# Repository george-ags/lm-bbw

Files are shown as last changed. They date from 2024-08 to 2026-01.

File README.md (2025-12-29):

# LM-BBW (brew-by-weight) for La Marzocco Linea Micra machine & Acaia Lunar scale

This given work is forked and based on Marcus Sorensen's "apollo" project 
(https://github.com/mlsorensen/apollo) - with big thanks and high appreciation !

LM-BBW helps land espresso on your Lunar scale. This project adds brew-by-weight and a small controller 
for La Marzocco Micra with Acaia Lunar. It may also work with other Acaia Bluetooth scales like Pyxis. 

I should fully rewrite some files (like control.py and pyacaia.py to port it to Debian 12/13+ with some improvements)

This project is more about scale integration than Micra integration. It cannot do flow profiling or other advanced 
control over the Micra, it is simply collecting data from the scale and acting as a proxy for the paddle switch.

**This is a hobby project, as such there is no support.** It is sort of a hack/proof of concept being beaten into shape.
Contributions are welcome, though this is very much designed to work according to my needs, for customization I'd 
suggest forking and making it your own.

# UPDATES

## Umbra support
I've added support for the Acaia Umbra scale, which is very similar to the Lunar scale, but it lacks a display and onboard
controls. This is ideal for integrations. Aside from being much less expensive. it is a bonus not to have to deal with 
accidentally touching controls. The full blank slab is also nice aesthetically.  Additionally, it has a "sleep" mode. This 
enables LM-BBW to just connect to the scale when needed, and the scale will go to sleep when disconnected - you don't need 
to touch the scale at all except occasionally to charge or clean it!

To accomodate this I've made one fundamental adjustment. I've comandeered the "target lock" toggle switch to become a 
"connect" button. In over a year I never used this button anyway. When depressed, it will connect to the scale and turn 
on the screen. When disabled it will disconnect and the screen will turn off. For a regular Lunar scale, simply leave the 
toggle depressed and you can continue to manage the system by turning on/off the Lunar as before.

## Horizontal display
This is a part of an effort to build a nicer enclosure, building the device into the top panel of the Micra. All of the
wiring and setup below still applies, with the exception of printing a new top panel and using 8mm push switches in place
of the toggle switch to select target weight.

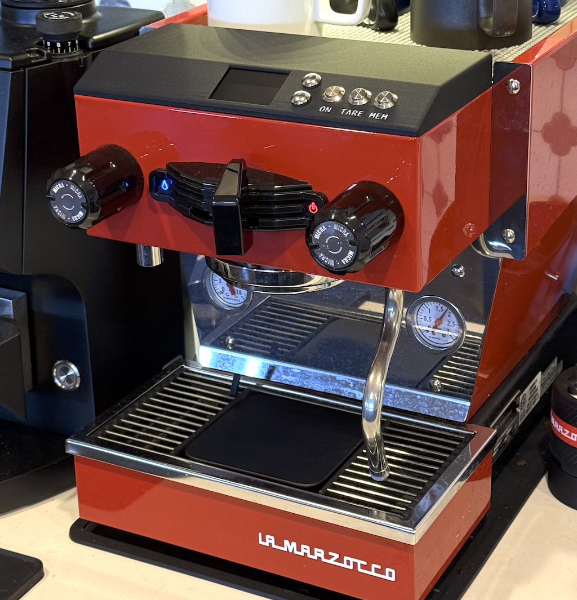
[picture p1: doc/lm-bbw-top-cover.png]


The "LM-bbw top cover" 3d printing models are in the doc folder.

In my setup I migrated from the Pi Zero 2W to the Raspberry Pi 5, which is overkill CPU-wise and I actually underclock to
1600MHz, but it gives smoother frame rates. I'm sure a Pi 4 or 3 would work too. I use the lite Raspbian image since we 
don't need a full GUI. I insulate the back of the device with tape and tuck it in the open space on the right near the 
steam wand.

I have monitored temperatures closely and not experienced a high enough temperature to throttle the Pi while installed. 
Consider printing the top cover in something more heat resistant like ABS or ASA. I printed in PLA Carbon Fiber for a 
nice texture, rated to withstand 55C, and I've coated the bottom inside shell with a thin layer of neoprene foam. So far 
I haven't seen the top exceed 42C.

I have replaced the top cover screws with M4-0.7 screws made of non-stainless and added 10mm magnets into the top
cover to hold it in place without visible fasteners.

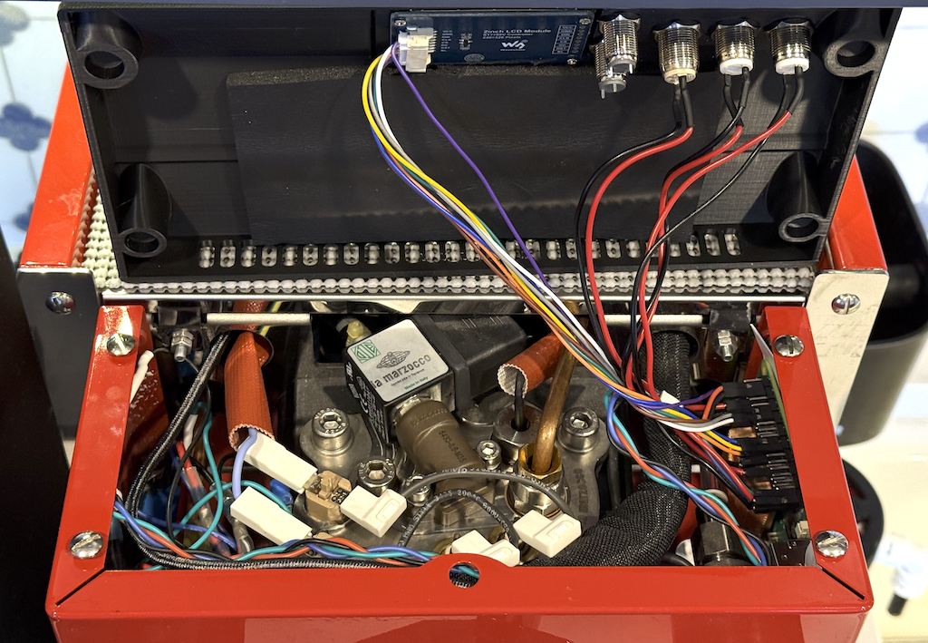
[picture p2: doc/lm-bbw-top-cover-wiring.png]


## Configuration variables
There are some new variables to control framerates and display orientation at `/etc/default/lm-bbw`, documented in the
comments of this file (aka `service/env` in this repo).

## Hardware

### Materials

Note that where external links are provided, they may not age well.

* A Raspberry Pi Zero 2W w/soldered header
* 5v relay w/3.3v compatible logic control
* 5v 2a power supply
* 2.1mm barrel jack connector/wiring harness
* pushbutton switch x 2
* toggle switch
* up/down rocker switch (or two pushbutton switches)
* 2" WaveShare 240x320 SPI display (or compatible)
* Screws - M2.0, M2.5 4mm length, or #3-24 in 1/4" length depending on your 3d printer tolerances
* Silicone 24AWG hook up wire
* Soldering tool and/or 2.54mm crimping set
* 3d printed enclosure, or self-provided alternative

### Controller

A Raspberry Pi was selected to accommodate easy adoption of existing Python libraries without having to
rework them to function on a microcontroller.  Ultimately this is more flexible in terms of expanding
functionality as well.

### Display

The software should support either the [WaveShare 2.0" display](https://www.waveshare.com/2inch-lcd-module.htm) 
or the [2.4" display](https://www.waveshare.com/2.4inch-lcd-module.htm). The 2.4" display seems to have worse
viewing angles and is less sharp, and display_size needs to be updated in `main()`. **For compatibility with the included enclosure, the 2" display should be used.**

### Relay

There isn't one specific relay to link to. Any 5v Arduino/Pi/ESP32 type relay should work. It will have 
common/NC/NO connections on the relay side and 5v/gnd/control pin on the controller side.

### Buttons

I use a momentary pushbutton switch for the tare and memory buttons, a toggle switch for the "scale connect" button,
and an up/down rocker switch for adjusting the target. The up/down rocker switch can be thought of as two momentary
switches with a common ground - you can use two separate buttons as well.

For compatibility with the included 3d printed enclosure, the buttons should be 12mm. The rocker switch should be
rectangular and support 19mm x 13mm opening. 

I found the quality of rocker switches a bit difficult, some had significant bounce leading to them being a bit tricky 
to use. I bought several kinds and used what worked best. The model I ended up using was `MXU1-2-123`.

### Wiring

I bought a crimping tool in order to finish off the connections with standard Dupont 2.54mm connectors for easy
wiring up to the Raspberry Pi header.



To simplify the wiring of power and controls between the Micra and the controller, I created a custom harness. This 
keeps the ground and power connections for the relay and switches in the Micra, with just 5v,ground and one wire
per IO going back to the controller (4 pins total).



The Micra paddle is accessible by removing the top four screws above the group head. Here, you would find a wiring
bundle containing black and white wires connecting to the paddle. These have bullet connectors which can be 
disconnected. You can insert the relay and Pi into this circuit to read the paddle state and control the Micra (or 
perhaps another device).

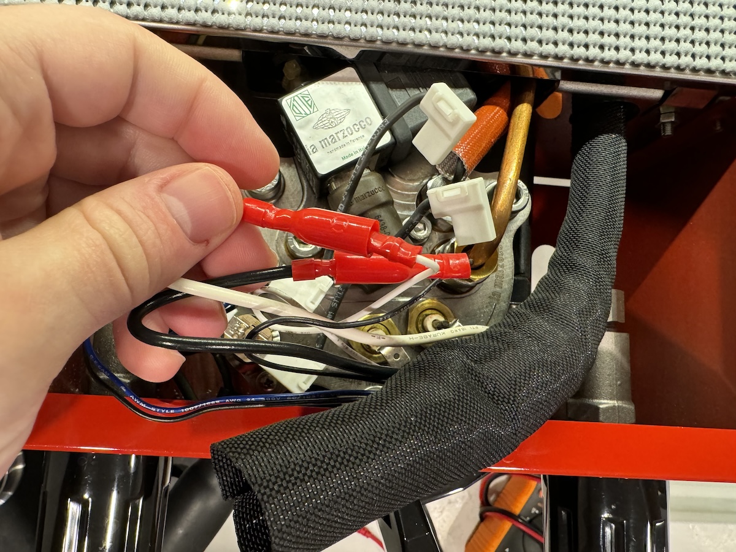
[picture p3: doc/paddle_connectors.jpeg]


### Enclosure

The enclosure STL file can be found [here](doc/LM-bbw_2inch_v2.stl). It may need fine tuning, depending on the accuracy
and tolerances of your printer.



Looking from the inside, the display mounts with four screws to the far side, along with the buttons.

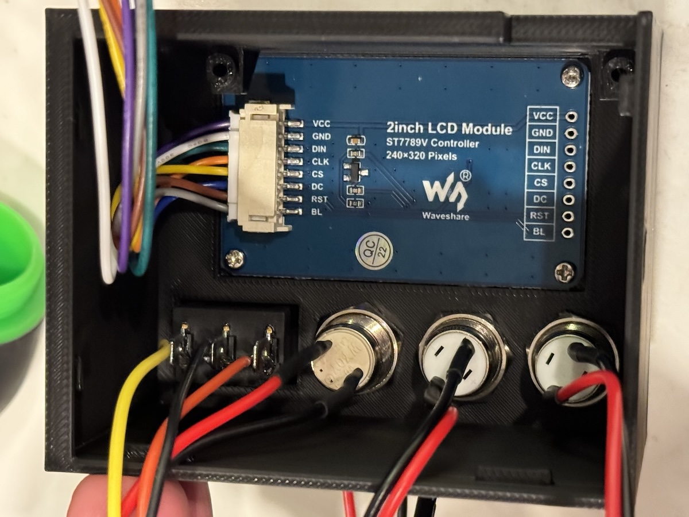
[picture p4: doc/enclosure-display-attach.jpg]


The Raspberry Pi mounts above the display, using the standoffs on the right. There are only two mounts for the Pi. 
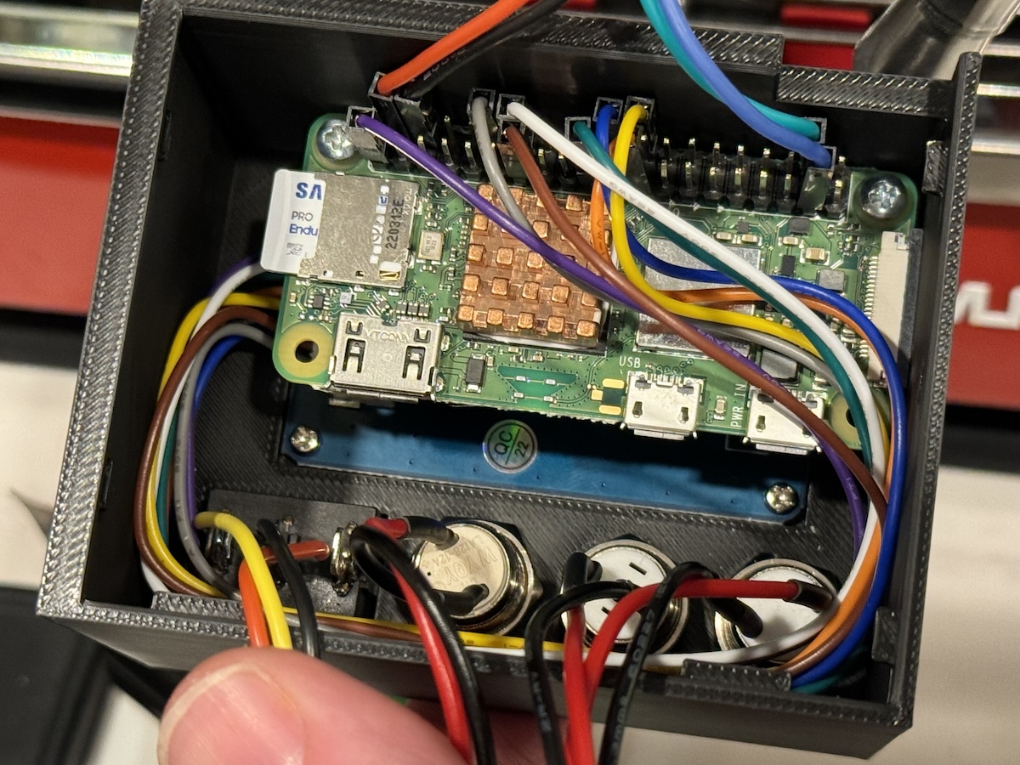
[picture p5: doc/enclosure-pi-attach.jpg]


In all cases be careful not to over-tighten. Ensure everything is connected properly. Route the wiring for the 
paddle/power through the cutout and then up into the group area through the open hole by the steam wand.

The backplate is designed to mount to the Micra on the right of the machine, using the large screw hole. Optional 8mm
magnets can be placed to aid installation and help secure the top of the plate.

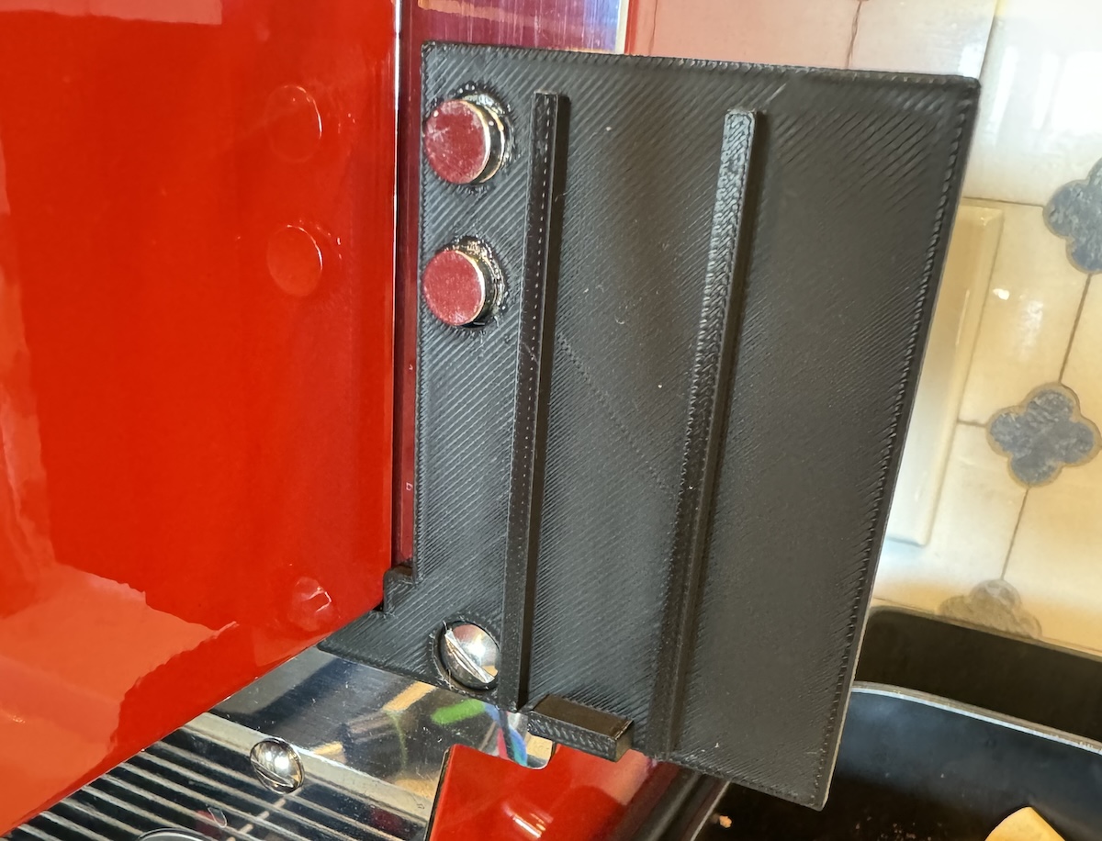
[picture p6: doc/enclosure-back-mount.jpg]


Then the enclosure hangs on the plate from the top clamshell-style. Once hung, a screw can be inserted to fasten the 
bottom of the enclosure to the plate.

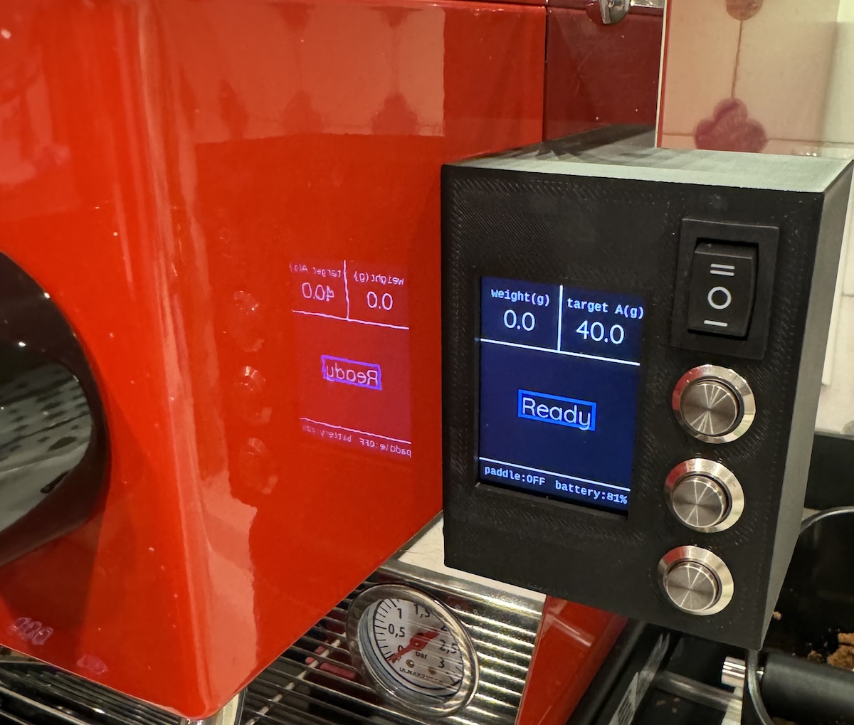
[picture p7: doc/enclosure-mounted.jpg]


## Software Installation

It is assumed you have a Raspberry Pi Debian distribution already installed. As of this writing,
Debian Bullseye is the recommended OS for the Pi Zero 2W. Other versions of Raspberry Pi may also
work.

### Display Driver

The SPI bus must be enabled to drive this display. Log into your Pi and run the following:

```commandline
sudo raspi-config
```

Choose Interfacing Options -> SPI -> Yes  to enable the SPI interface

Next, we want to release memory from the GPU for system use and thus change / set it to 16M.
(Note in Debian 11 it was in `raspi-config`, under Performance -> GPU Memory limit)
```commandline
sudo nano /boot/firmware/config.txt
```

Scroll to the bottom of the file and add, or modify, (best is under section [all]) the following line:
```commandline
gpu_mem=16
```

Finally, we want to disable the login UI. Under System Options -> Boot / Auto Login choose "Console" 

```commandline
sudo reboot
```

### Software dependencies

```commandline
sudo apt install python3-pandas python3-pip libglib2.0-dev git
sudo pip3 install bleak --break-system-packages
```

#### LM-BBW Software Installation and Activation

```
git clone https://github.com/george-ags/lm-bbw.git
cd lm-bbw
sudo mkdir -p /opt/lm-bbw/web
sudo cp -r lm-bbw.py lib /opt/lm-bbw
sudo chmod +x /opt/lm-bbw/lm-bbw.py
sudo cp service/lm-bbw.service /etc/systemd/system
sudo cp service/env /etc/default/lm-bbw
sudo systemctl daemon-reload
sudo systemctl enable --now lm-bbw
```

By default, the software scans for any Lunar device in the vicinity and connects to it. There is no simple
way to set a specific scale MAC address yet.

#### If it FAILS to start
 - check in Journalctl if Bluetooth adapter is found and it's powered On:
```commandline
bluetoothctl show
```
You should see Powered: yes.

If you have an issue follow the following steps:
##### Enable Bluetooth adapter

Clear the "Saved" Block State
Linux remembers if you turned Bluetooth off previously and restores that state on boot. You need to clear this memory.

Run these commands one by one:

Unblock everything physically and via software
```commandline
sudo rfkill unblock all
```

Force the bluetooth service to start
```commandline
sudo systemctl enable bluetooth
sudo systemctl start bluetooth
```

Force power on via the control tool
```commandline
sudo bluetoothctl power on
```

Add a "Force ON" Boot Rule (The Fix) - add a hardware rule that forces the power ON the moment the chip wakes up.
Create a new udev rule file:
```commandline
sudo nano /etc/udev/rules.d/10-local.rules
```
Paste this exact line into the file:
```commandline
ACTION=="add", KERNEL=="hci0", RUN+="/usr/bin/bluetoothctl power on"
```
Save and exit

Reboot the Pi:

```commandline
sudo reboot
```

Verify
After the reboot, wait 30 seconds and run:
```commandline
bluetoothctl show
```
You should see Powered: yes.

If it still says Powered: no: It means the UART driver for the Pi is failing to load. Check the status of the hardware attachment service and try to troubleshoot:
```commandline
sudo systemctl status hciuart
```

## Software Development

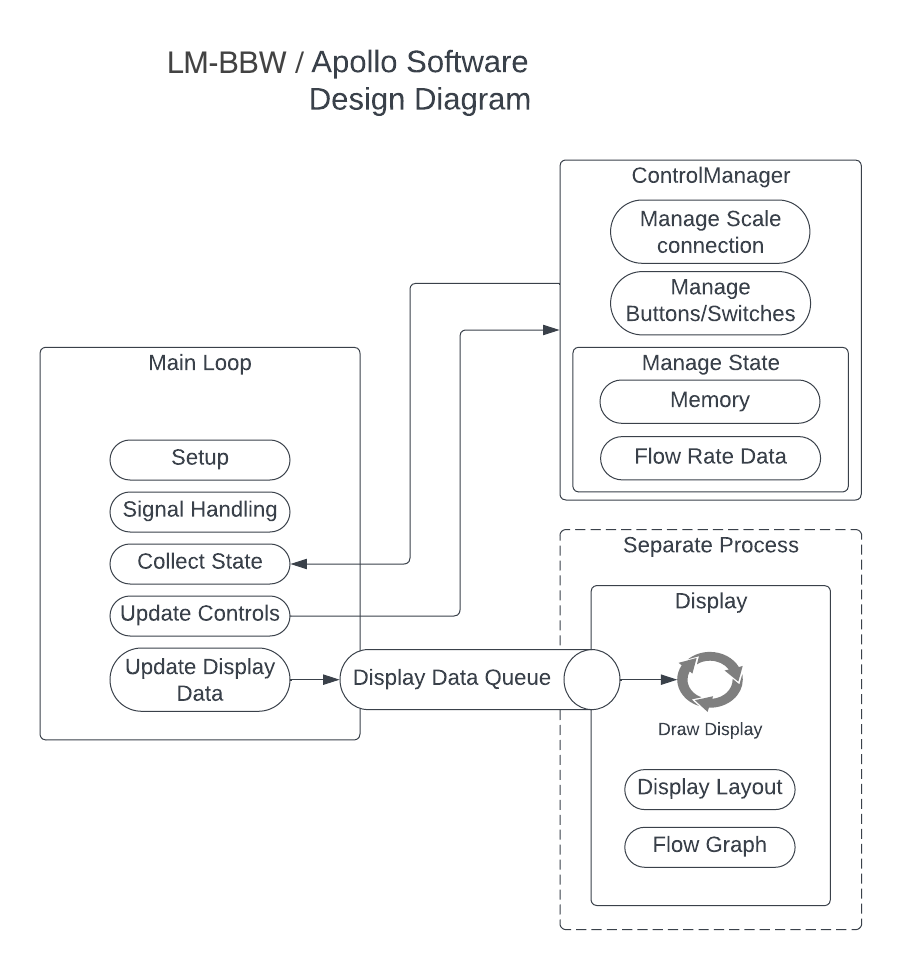
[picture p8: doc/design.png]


### ControlManager

This controls the physical devices. It defines buttons, keeps state, and maintains scale connectivity.

### Display

Display class is responsible for defining how graphics are drawn, and updating the physical display as well as saving
images of finished shots. It runs in a separate process so that display refreshes aren't blocked on anything else. To
achieve this, current data is pushed onto a queue which is constantly read from - the queue is drained on each
refresh and the latest data is displayed.

This was originally using matplotlib, which was CPU intensive and slow. Several other libraries were investigated, but 
they all had their own drawbacks (dependencies), optimization for webpage viewing, performance etc. In the end it was 
decided drawing the graph using simple lines was sufficient and performant.

### Main loop

The main loop is responsible for basic logic of setting up a Display and ControlManager, then orchestrating data
collection and state updates.

### Display

A single frame can be generated using `test_display.py` for design changes to the display. Running `pytest` should be
sufficient to discover this test, run it, and open the resulting image on your workstation.

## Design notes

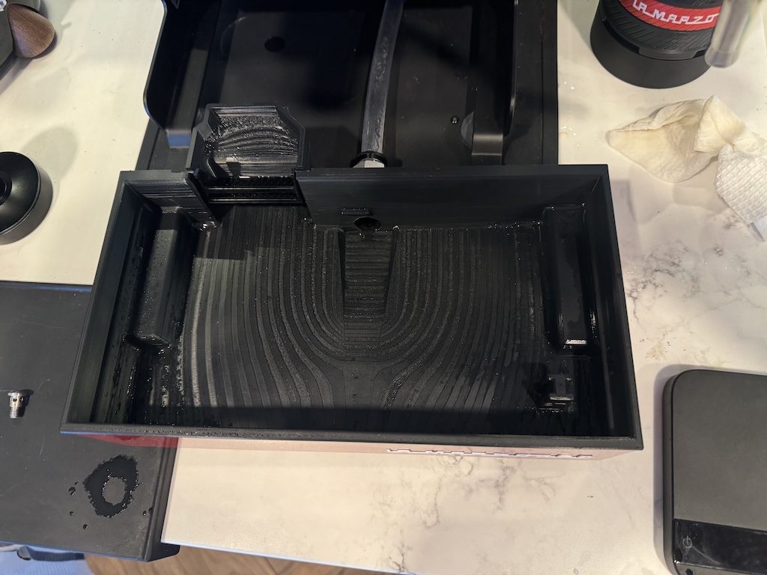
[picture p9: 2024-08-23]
tray-models/photos/tray.jpeg

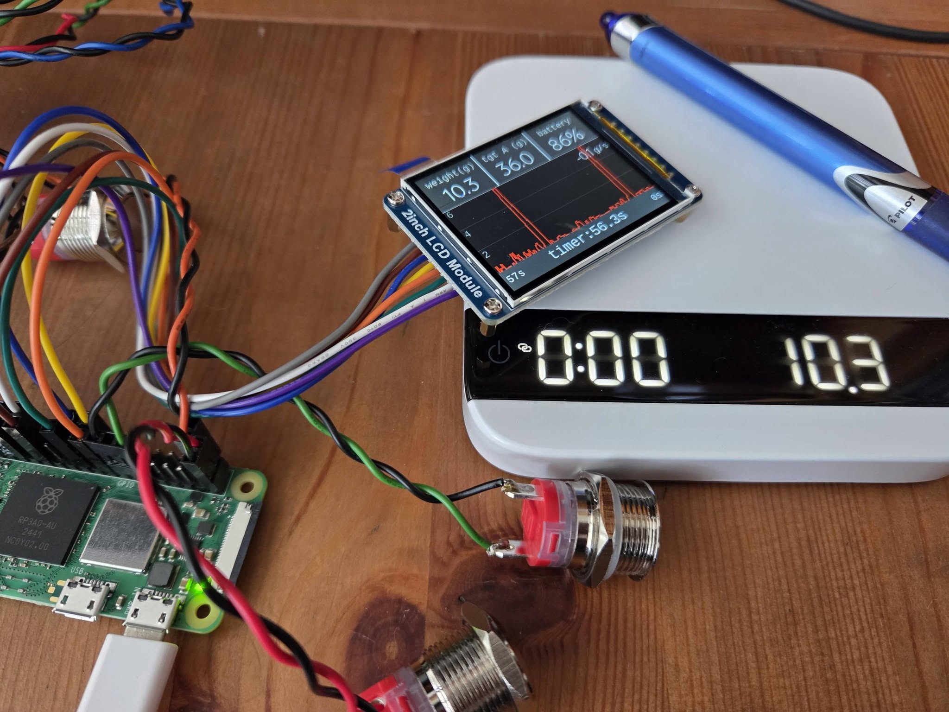
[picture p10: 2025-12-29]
doc/in-work-2.jpg

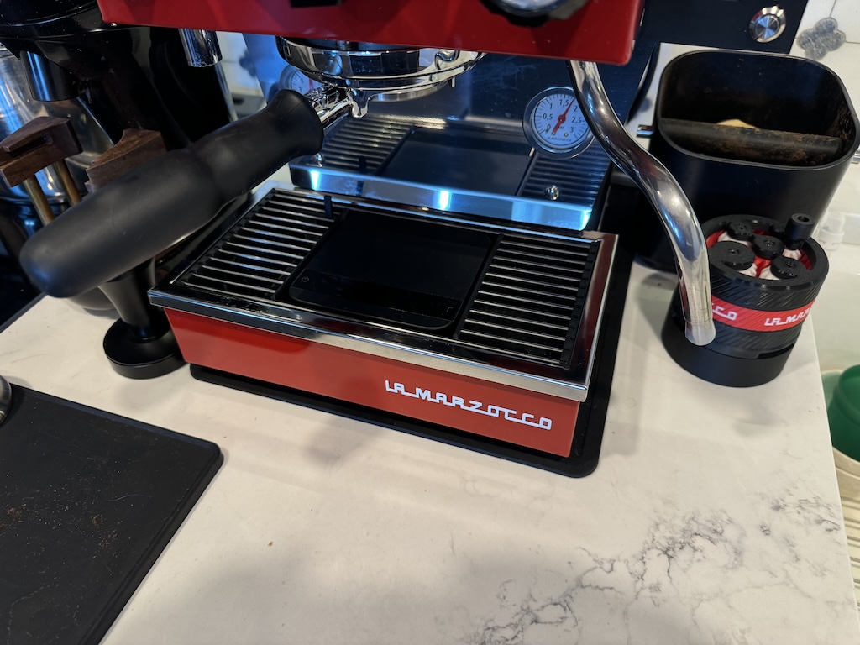
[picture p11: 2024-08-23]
tray-models/photos/flush.jpeg

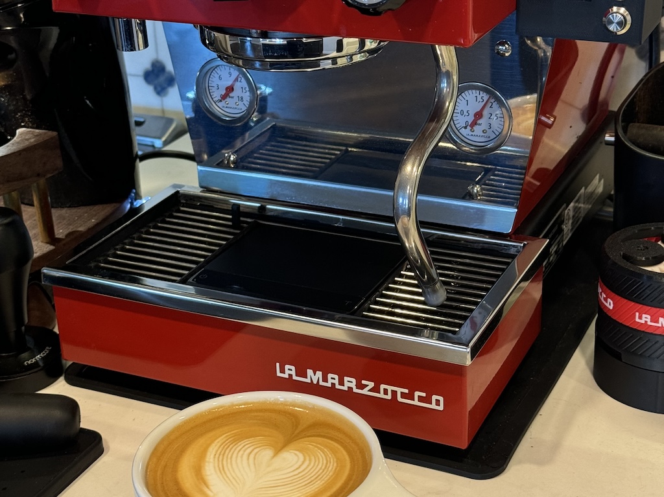
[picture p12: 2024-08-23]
tray-models/photos/recessed.jpeg

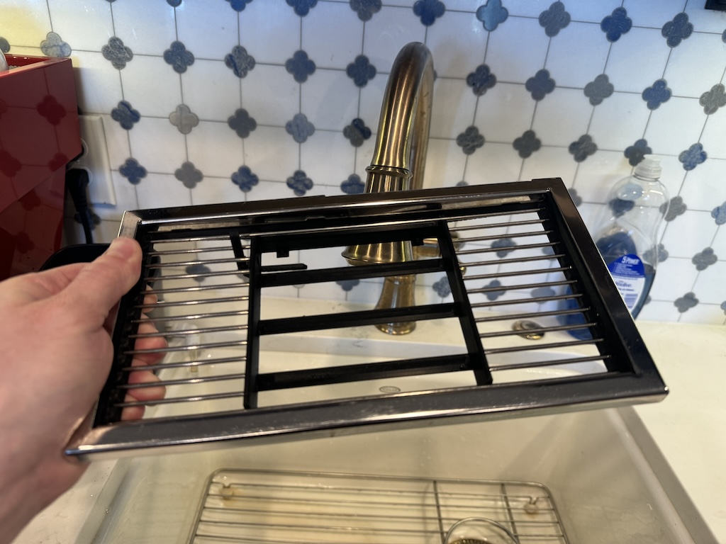
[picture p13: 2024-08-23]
tray-models/photos/recessed2.jpeg

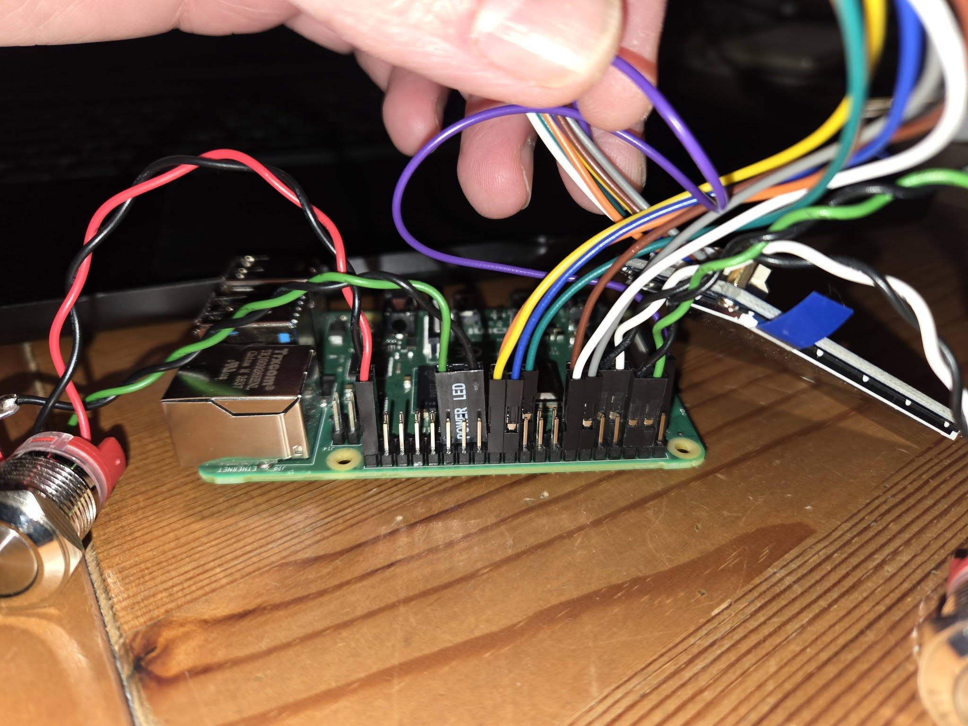
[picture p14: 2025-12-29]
doc/in-work-1.jpg

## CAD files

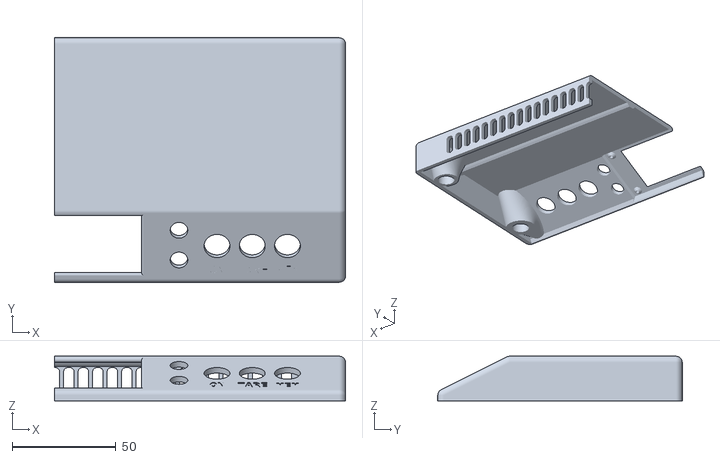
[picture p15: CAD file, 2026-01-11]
doc/LM-top-big-round.stl
140.4 x 118.0 x 21.5

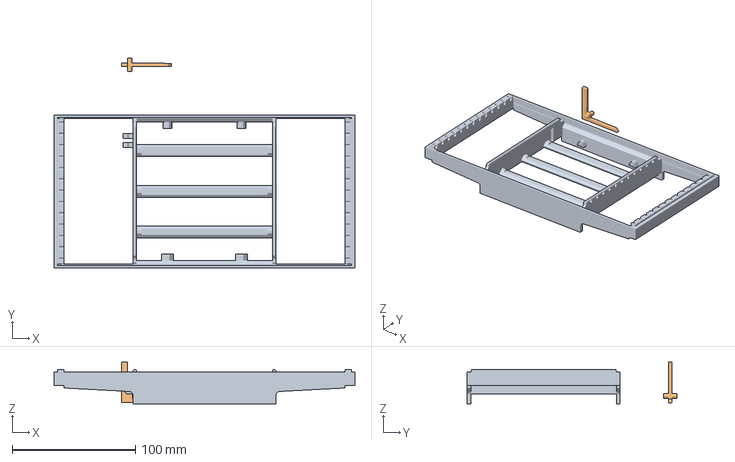
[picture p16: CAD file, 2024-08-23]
tray-models/Micra Tray Grille Flush.3mf
244.0 x 169.9 x 34.0 mm
Body_01_(1)****

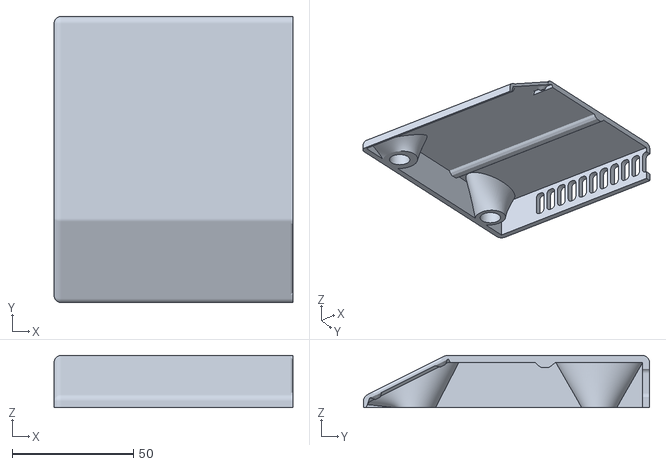
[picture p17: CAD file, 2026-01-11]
doc/LM-top-small.stl
98.6 x 118.0 x 21.5

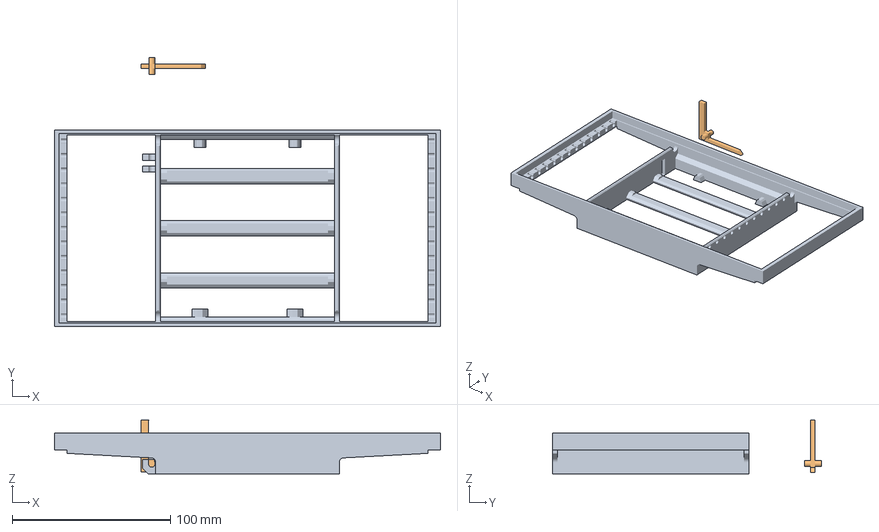
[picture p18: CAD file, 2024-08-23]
tray-models/Micra Tray Grille - extra 8mm.3mf
244.0 x 169.9 x 34.0 mm

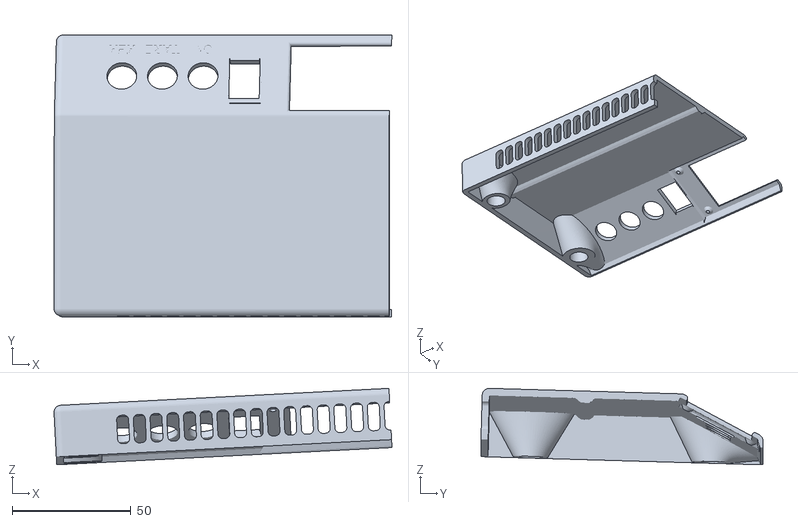
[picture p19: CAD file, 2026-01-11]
doc/LM-top-big-square.stl
142.3 x 118.8 x 32.1

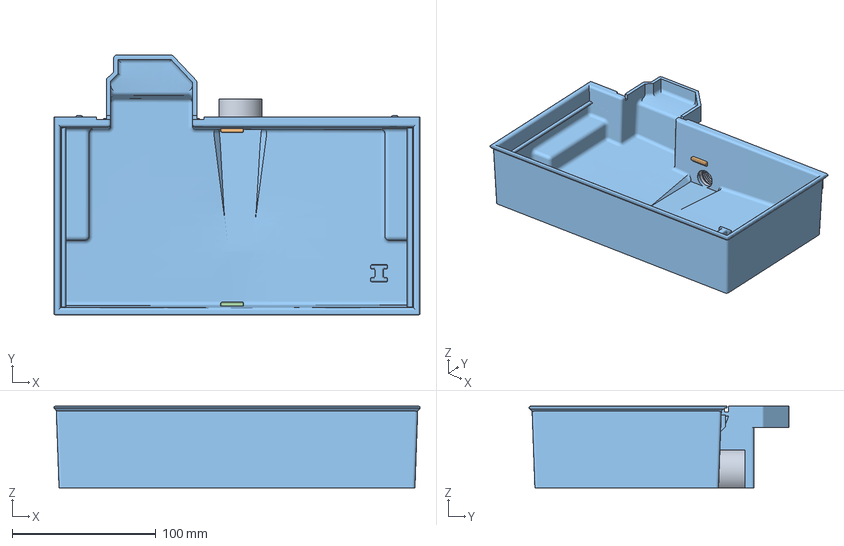
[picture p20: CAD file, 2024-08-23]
tray-models/Micra Drain Tray with half-inch NPT.3mf
255.0 x 181.0 x 57.0 mm

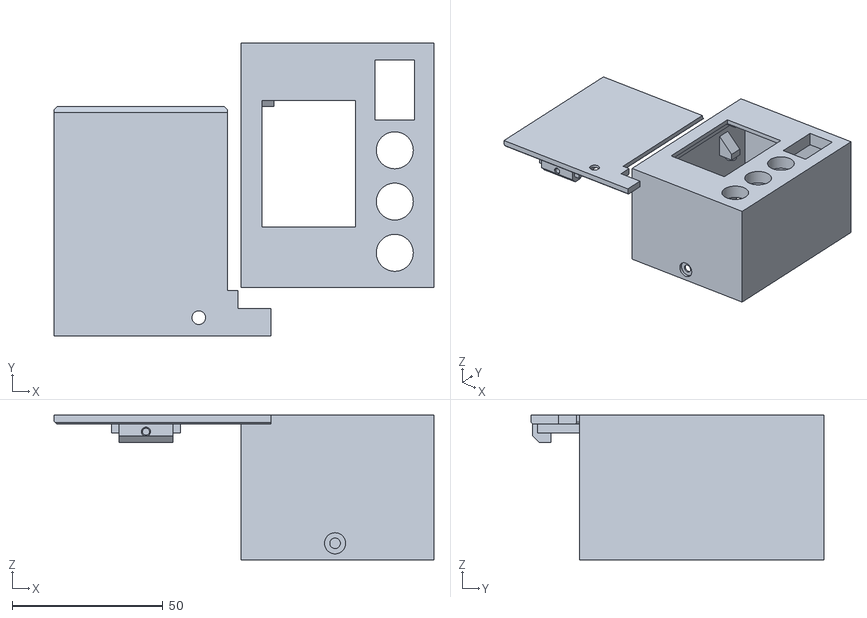
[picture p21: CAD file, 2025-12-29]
doc/LM-bbw_2inch_v2.stl
126.0 x 97.0 x 48.0

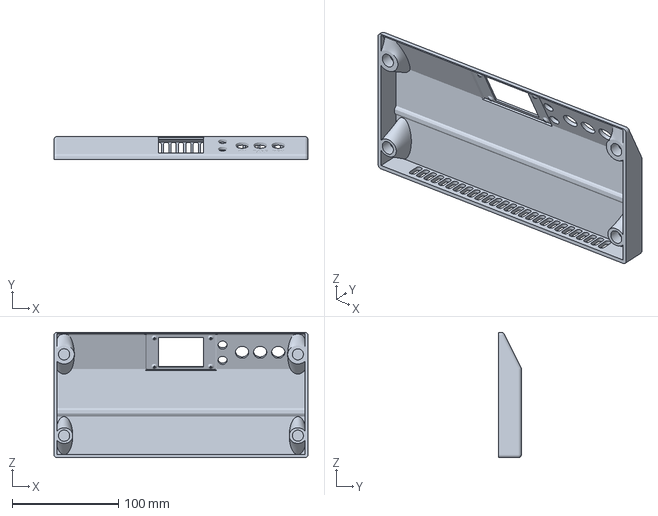
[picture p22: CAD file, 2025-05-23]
doc/LM-bbw top cover v1.1.3mf
239.0 x 21.5 x 118.0 mm

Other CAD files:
tray-models/Micra Drain Tray with half-inch NPT.x_t
tray-models/Micra Tray Grille - extra 8mm.x_t
tray-models/Micra Tray Grille Flush.x_t

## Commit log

2025-05-12 feat: repurpose toggle button for scale connection
2025-05-16 feat: add function to render frames that are wide
2025-05-23 chore: add images for top cover
    [Apollo top cover v1.1.3mf]
2025-05-30 fix: improve target inc/dec button presses
2025-12-29 changing apollo to more pragmatic name bbw (brew by weight)
    [LM-bbw top cover v1.1.3mf, LM-bbw_2inch_v2.stl]
2025-12-29 adding pull-up resistor of 6.8kOm
2026-01-01 using symbols for battery and paddle instead of borring text
2026-01-01 update the _heartbeat_loop to send a 'Notification Request' which triggers a settings update every 60 seconds in order to get the battery level updated
2026-01-01 fix for the battery level getting stuck
2026-01-01 improving the paddle and battery icons
2026-01-07 for Landscape Mode:
    Header: Fonts are ~22% smaller (reduced from 36pt to 28pt).
    Header Content: The 3rd column now displays the Shot Timer instead of the Battery.
    Footer Added: A footer bar has been added to the bottom (just like Portrait), containing the Paddle Switch (left) and Battery (right).
2026-01-07 updated the Landscape Header logic to dynamically calculate the width of the word timer and center it perfectly in the third column, replacing the hardcoded left-aligned coordinate.
2026-01-07 This confirms that despite the "Double-Tap," the notification channel sometimes fails to open, leaving the connection in a "Zombie" state (Connected, but deaf).
    To solve this, implement Validation & Auto-Kill.
    modified lib/pyacaia.py to add a "Connection Verifier" step at the end of the connection sequence.
    The Check: After finishing the handshake, the code now pauses for 2 seconds to listen for incoming data.
    The Trigger: It checks self.battery. Since Acaia scales never operate at true 0% battery (they turn off way before that), a value of 0 confirms no data is coming in.
    The Action: If battery == 0, it immediately aborts the connection (disconnects). This forces the main loop to detect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
2026-01-10 fixed the bug preventnig the scale to go to sleep. need to stop the weight readings from resetting the timer. The system should only stay awake if we are interacting with it (Buttons, Paddle) or if t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
2026-01-11 completely stop the PWM signal when the screen sleeps. This cuts power to the backlight pin entirely. We will then restart the PWM signal only when data arrives.
2026-01-11 completely stop the PWM signal also when the service is restarted and no scale is connected - i.e. in the screen init
2026-01-11 split top cases with round and square 'arrow' buttons
    [LM-top-big-round.stl, LM-top-big-square.stl, LM-top-small.stl]
2026-01-11 pic of the latest top enclosure
2026-01-11 Based on the journalctl logs, the specific error [org.freedesktop.DBus.Error.AccessDenied] Client tried to send a message other than Hello without being registered confirms that the system is still r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
2026-01-11 Since the standard "clean" context manager is failing to release the D-Bus resources on the specific hardware/OS setup (causing the "Maximum Connections" error), we need to take a more aggressive app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
2026-01-13 adding display of average flow rate at the end of brewing
2026-01-14 improve the average flow rate calculation: freeze (latch) the calculation the exact moment the paddle turns OFF, calculate the value once, store it, and stick to it until the next shot starts
2026-01-23 implementing auto-sleep again - now with simplepyble: if no weight change or button pressed, disconnect after IDLE_TIMEOUT, wait for SLEEP_PAUSE, and then resume the scanning
2026-01-23 decouple refresh functionalities and define 3 instead of current 1: REFRESH_RATE: Controls only the main loop speed (how fast we poll hardware).
    GRAPH_HISTORY_SECONDS: Controls how many seconds of data remain on the graph (default: 60s).
    FLOW_SMOOTHING_FACTOR: Controls how many data points are averaged for the line drawing (higher = smoother but more lag).
2026-01-27 in web server/page: do not display back to the parent directory if the current one is '/'
2026-01-27 Fix for "Zombie" connection when the scale was technically "Connected" (according to the internal flag), but the Bluetooth adapter had stopped transmitting data.
    Since the SimplePyBLE write command is "fire-and-forget" (Write Without Response), it is very fast.
    The delay to coffee starting will be negligible (milliseconds) unless the Bluetooth stack is completely dead.
    Change:
    1. Check Connection First.
    2. If Connected: Send Tare command before the Relay.
    3. If Disconnected: Skip Tare and fire Relay immediately.
